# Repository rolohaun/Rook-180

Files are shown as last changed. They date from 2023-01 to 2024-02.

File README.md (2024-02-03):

# Rook 180

# PLEASE NOTE THIS IS OUT OF DATE

NEWEST VERSION HERE
https://www.printables.com/model/748800-bastion-3d-printer

Welcome to the DIY 3D Printer called Rook 180!

This is a 180x180 build volume printer based on the original Rook

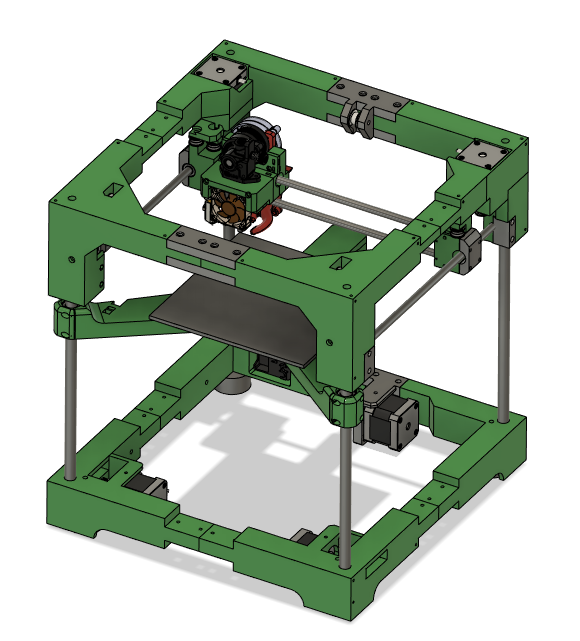
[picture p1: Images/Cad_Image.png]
image of Rook 3D Printer


### PLEASE NOTE THIS PRINTER IS A WORK IN PROGRESS!

The goal of this printer is to make a cheap easy to build 3D printer than can be built by anyone.

## Features:

- 180 x 180 Build Volume
- 3D Printed Frame
- CoreXY
- Triple Belted Z
- Only Roughly $400 USD in cost

## Build F.A.Q

- I print with 3 walls and 15 percent infill, if you want stronger go 4 walls 20 percent infill should be plenty
- I use PLA for the prototype and it worked well, ABS and ASA would be great too
- This printer uses all F695 bearings with some 20t idlers for the belted Z

### [BOM on Google Drive](https://docs.google.com/spreadsheets/d/1l0jujA7NeqoZIqLFWoQa9GS_q04f8Wfkya9Il5d2ubA/edit#gid=0)

### [Support me on Patreon](https://www.patreon.com/rolohaun)

### [My Discord](https://discord.gg/jJSwTtkX6T)

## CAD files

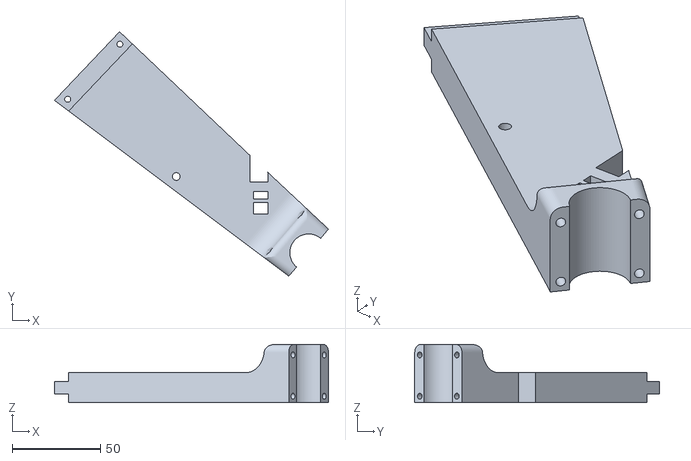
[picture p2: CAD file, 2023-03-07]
STL/Bed/Right_Bed_Mount.stl
155.0 x 138.3 x 33.0

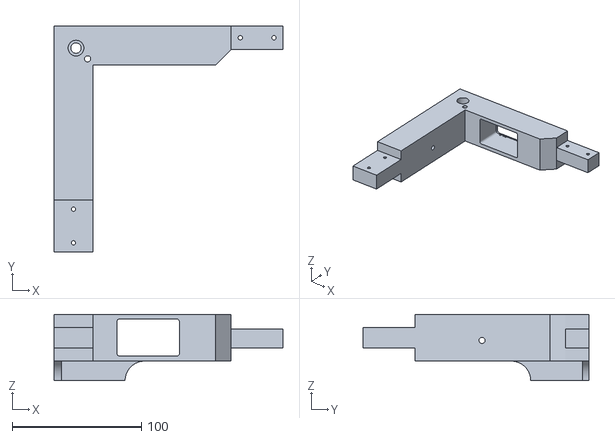
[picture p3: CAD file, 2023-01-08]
STL/Frame/Bottom Frame/BOTTOM_Rear_Left_Bottom_Frame.stl
177.0 x 174.5 x 51.1

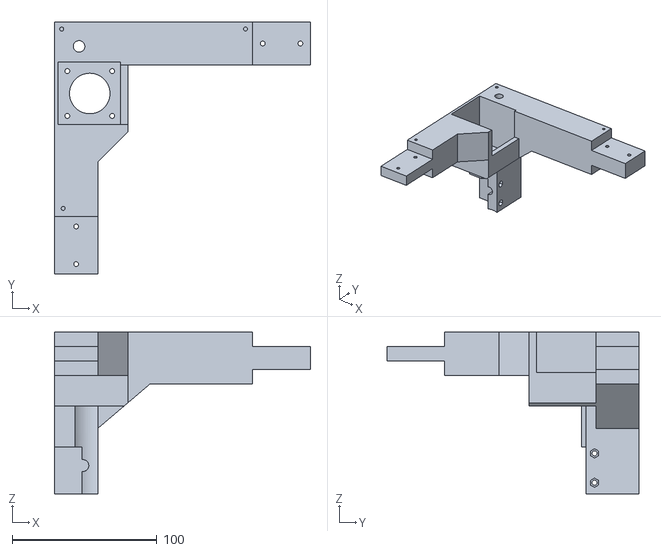
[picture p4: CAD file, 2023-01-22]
STL/Frame/Top Frame/TOP_Left_Rear_Frame.stl
177.0 x 174.5 x 112.0

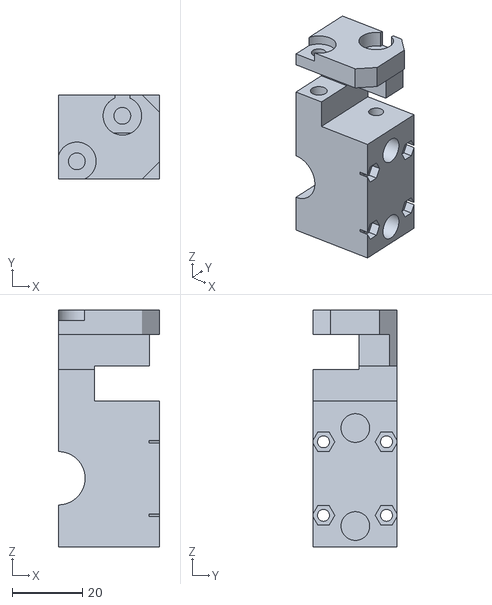
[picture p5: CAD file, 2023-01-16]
STL/Gantry/Y_Carriage_Left.stl
28.9 x 24.0 x 67.7

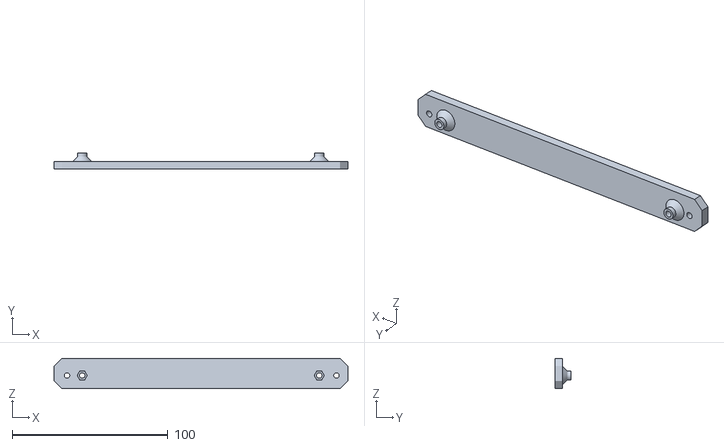
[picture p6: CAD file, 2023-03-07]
STL/MKS_Monster_8_Mount.stl
188.5 x 10.5 x 19.4

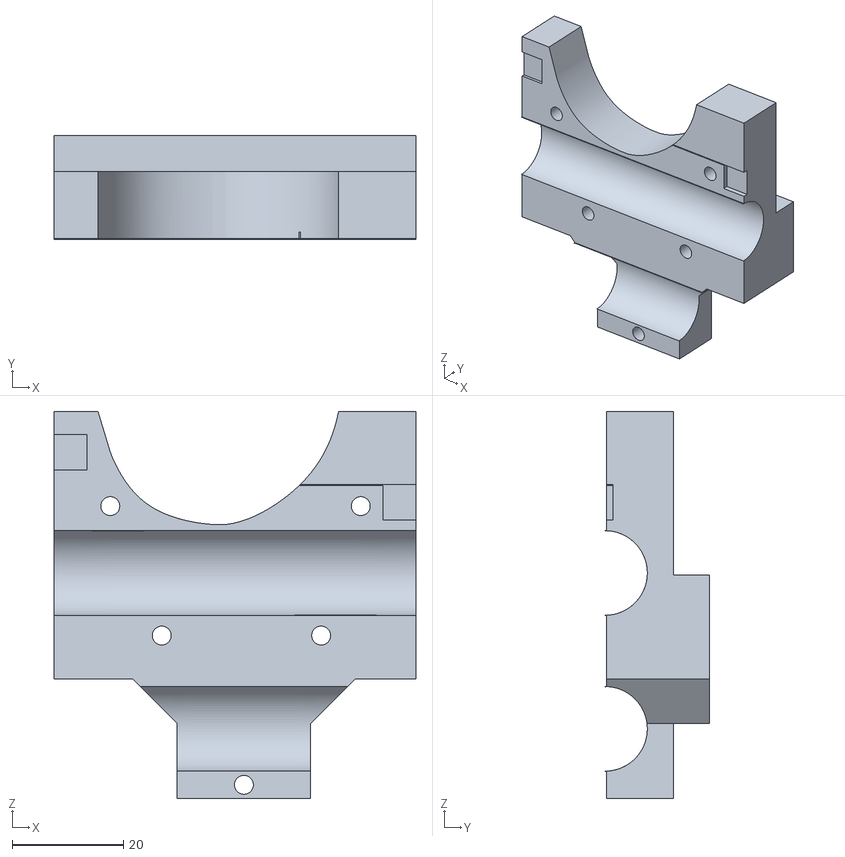
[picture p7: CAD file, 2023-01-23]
STL/Toolhead/X_Carriage_Rear.stl
65.0 x 18.7 x 69.5

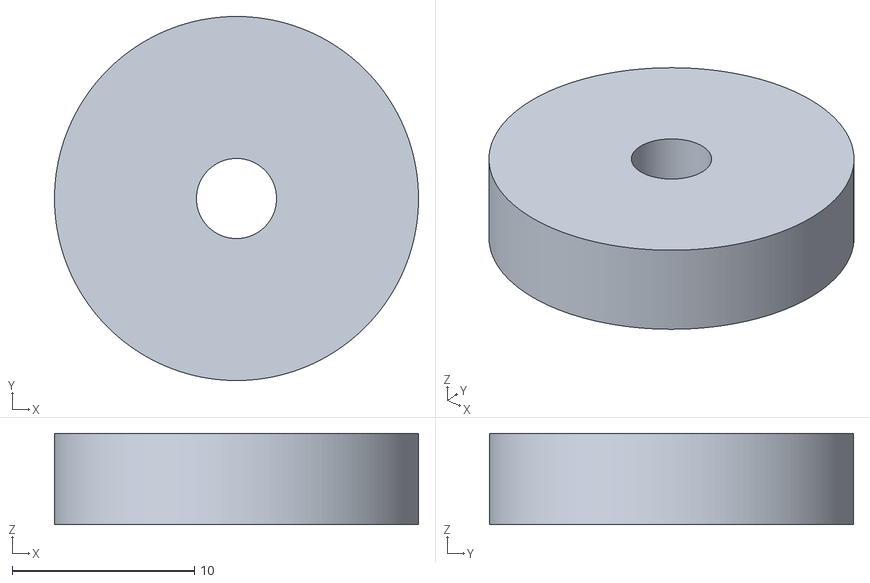
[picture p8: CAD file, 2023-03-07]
STL/Bed/4 x Prusa_Bed_Mount.stl
20.0 x 20.0 x 5.00

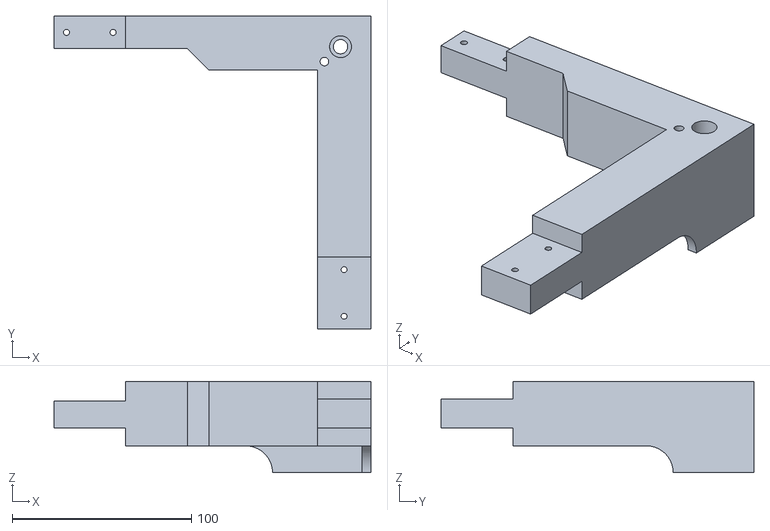
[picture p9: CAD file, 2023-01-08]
STL/Frame/Bottom Frame/BOTTOM_Rear_Right_Bottom_Frame.stl
177.0 x 174.5 x 51.1

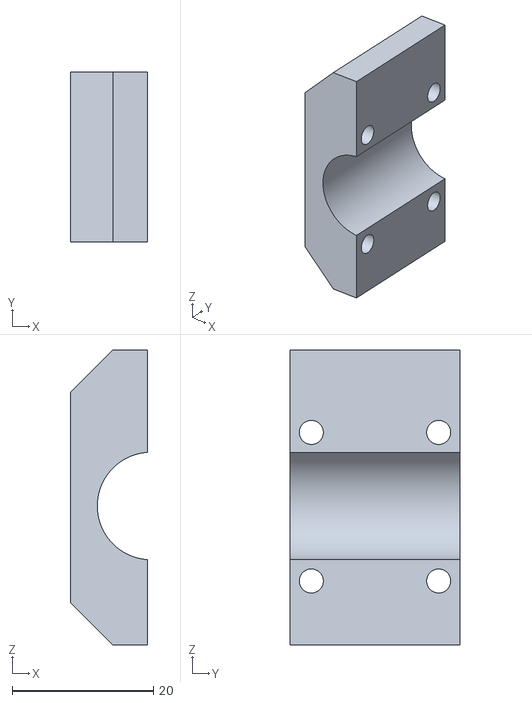
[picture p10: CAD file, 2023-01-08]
STL/Gantry/Y_Left_Carriage_Clamp.stl
10.9 x 24.0 x 41.7

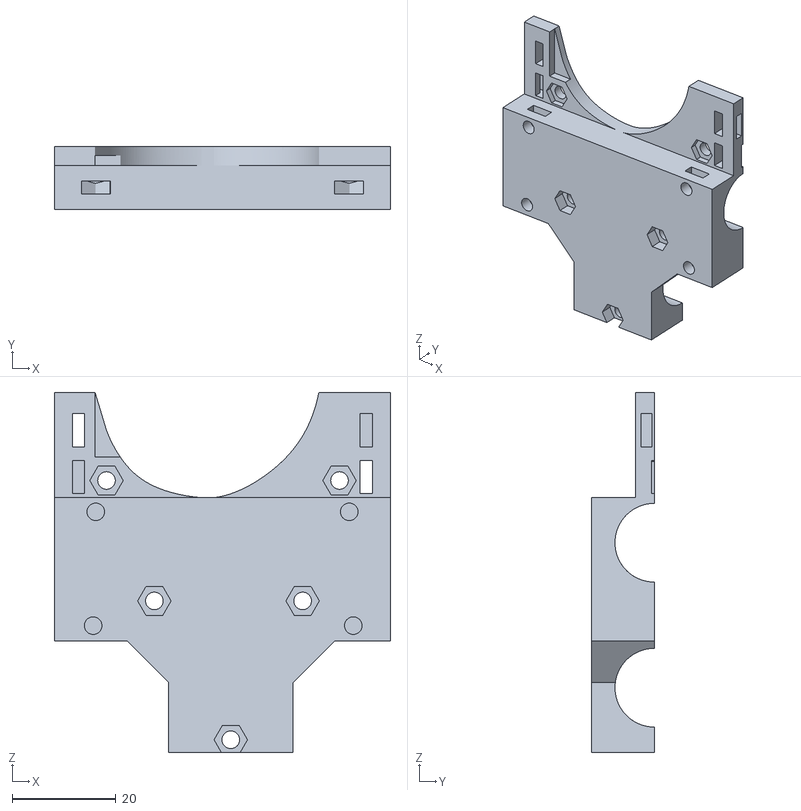
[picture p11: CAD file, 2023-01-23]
STL/Toolhead/X_Carriage_Front.stl
65.0 x 12.2 x 69.5

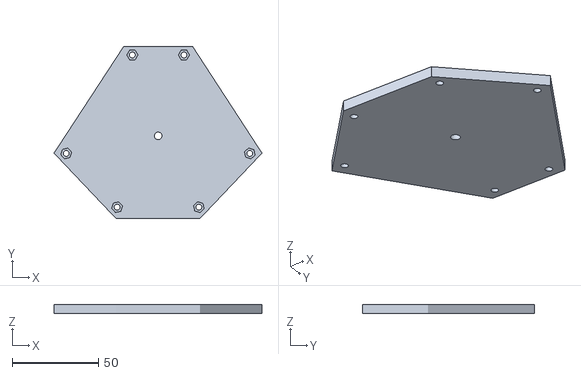
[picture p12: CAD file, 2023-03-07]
STL/Bed/Bed_Center_Top.stl
120.5 x 99.8 x 5.00

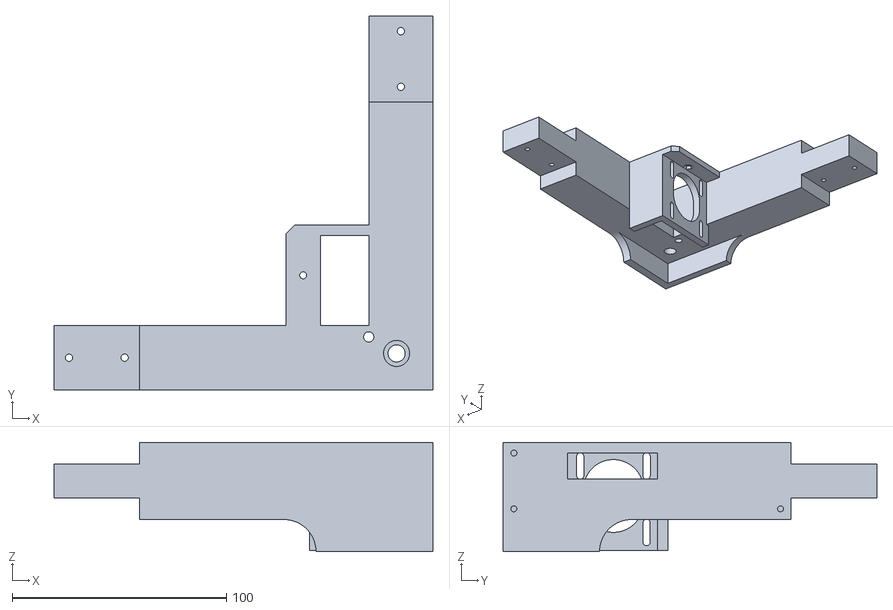
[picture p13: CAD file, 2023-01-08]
STL/Frame/Bottom Frame/BOTTOM_Front_Right_Bottom_Frame.stl
177.0 x 174.5 x 51.1

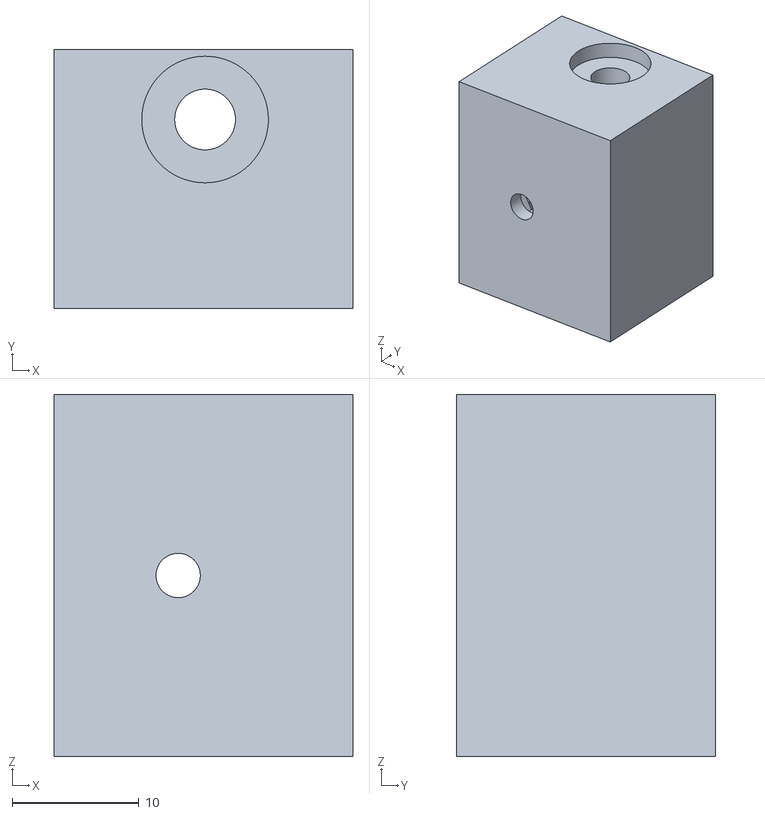
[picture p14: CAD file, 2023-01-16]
STL/Frame/Top Frame/Right_Idler_Cartridge.stl
23.6 x 20.5 x 28.6

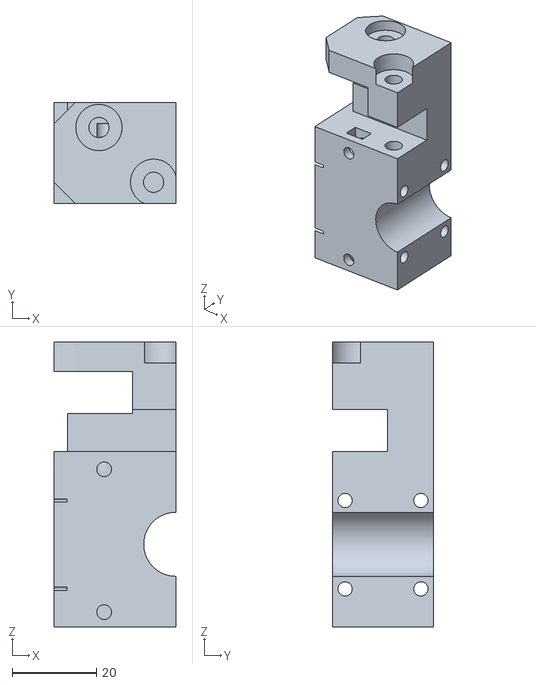
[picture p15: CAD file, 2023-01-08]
STL/Gantry/Y_Carriage_Right.stl
28.9 x 24.0 x 67.7

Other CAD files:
STL/Frame/Top Frame/TOP_Right_Rear_Frame.stl
STL/Toolhead/Toolhead_TD6S.stl
STL/Bed/Left_Bed_Mount.stl
STL/Frame/Bottom Frame/BOTTOM_Front_Left_Bottom_Frame.stl
STL/Bed/Bed_Center_Bottom.stl
STL/Bed/Left_Bed_Bearing_Clamp.stl
STL/Bed/Rear_Bed_mount.stl
STL/Bed/Right_Bed_Bearing_Clamp.stl
STL/Frame/Bottom Frame/1 x Rear_Lower_Brace_With_Motor_Mount.stl
STL/Frame/Bottom Frame/3 x Frame_Lower_Brace.stl
STL/Frame/Bottom Frame/3 x Frame_Upper_Brace.stl
STL/Frame/Top Frame/1 x Rear_Upper_Brace.stl
STL/Frame/Top Frame/3 x Frame_Lower_Brace.stl
STL/Frame/Top Frame/3 x Frame_Upper_Brace.stl
STL/Frame/Top Frame/Front_Left_Y_Frame_Clamp.stl
STL/Frame/Top Frame/Front_Right_Y_Frame_Clamp.stl
STL/Frame/Top Frame/Left_Idler_Cartridge.stl
STL/Frame/Top Frame/Rear_Left_Y_Frame_Clamp.stl
STL/Frame/Top Frame/Rear_Right_Y_Frame_Clamp.stl
STL/Frame/Top Frame/TOP_Left_Front_Frame.stl
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

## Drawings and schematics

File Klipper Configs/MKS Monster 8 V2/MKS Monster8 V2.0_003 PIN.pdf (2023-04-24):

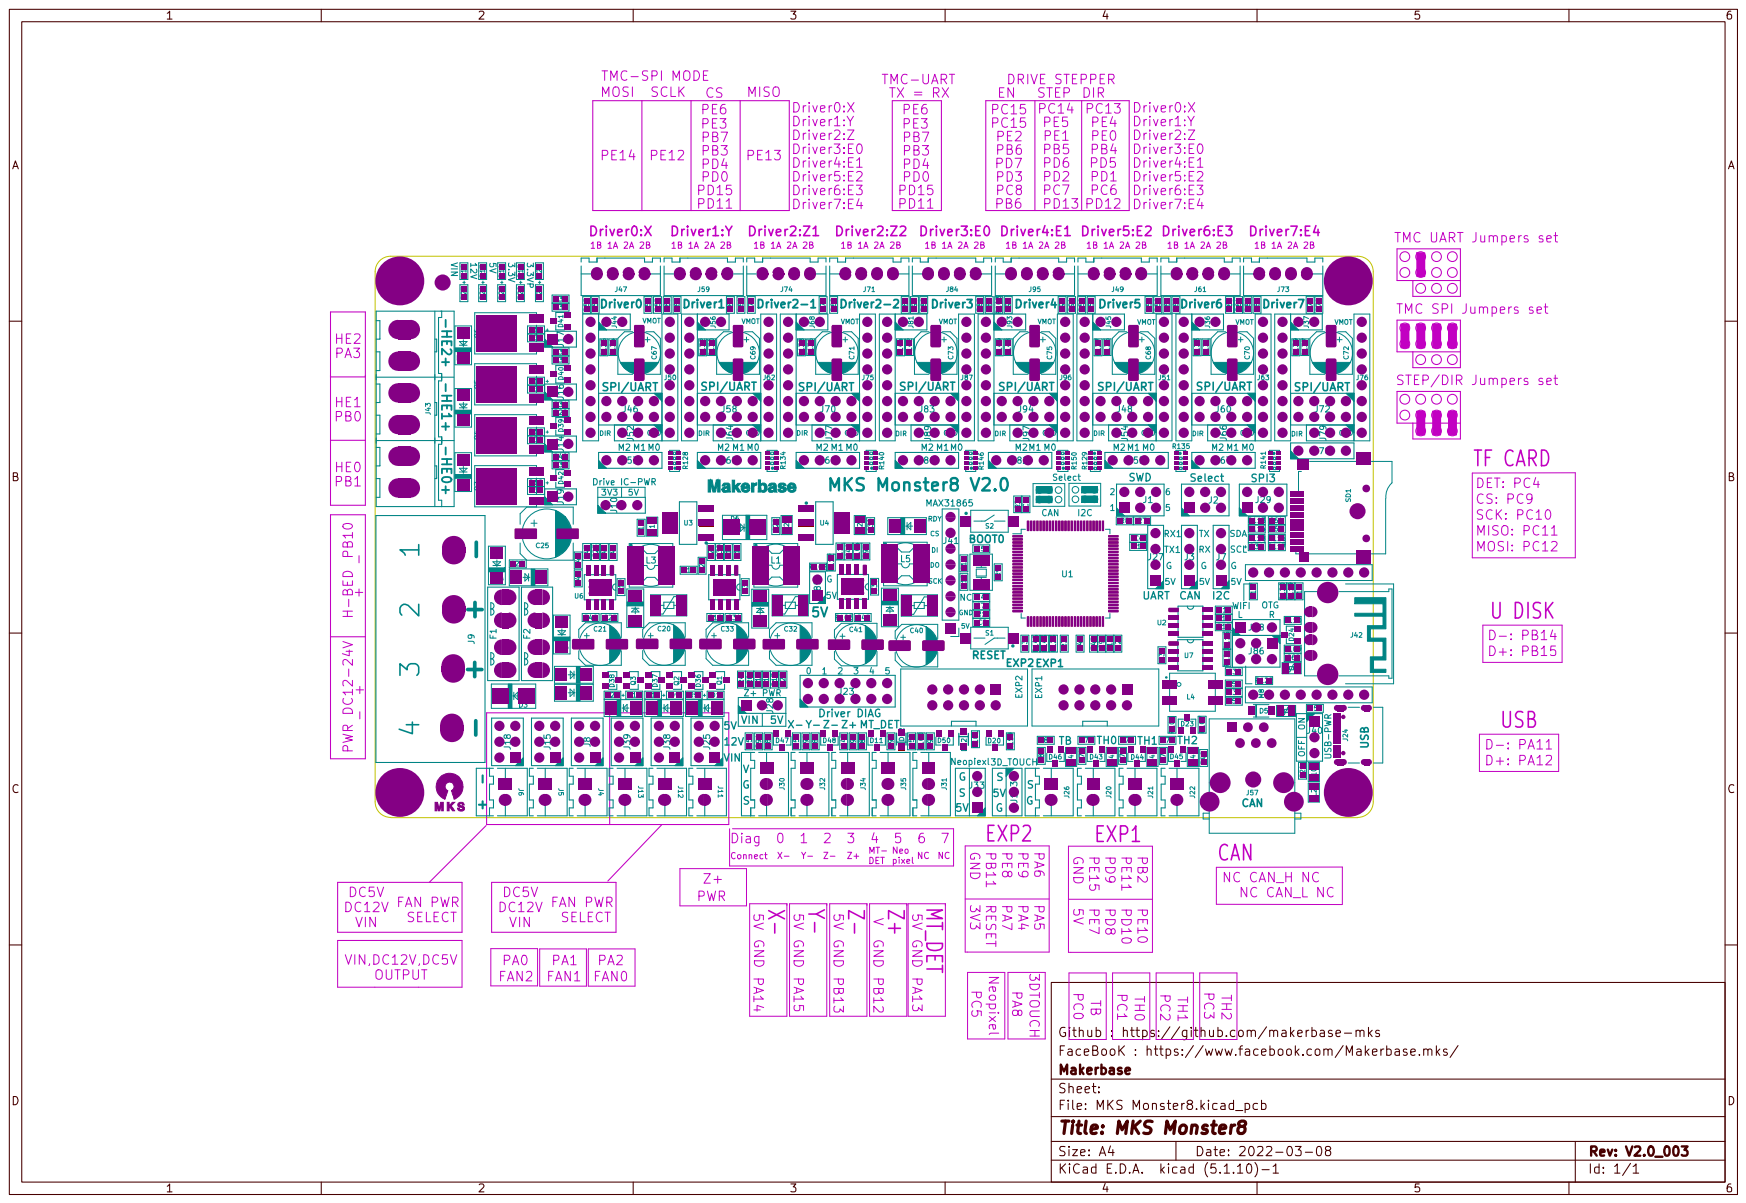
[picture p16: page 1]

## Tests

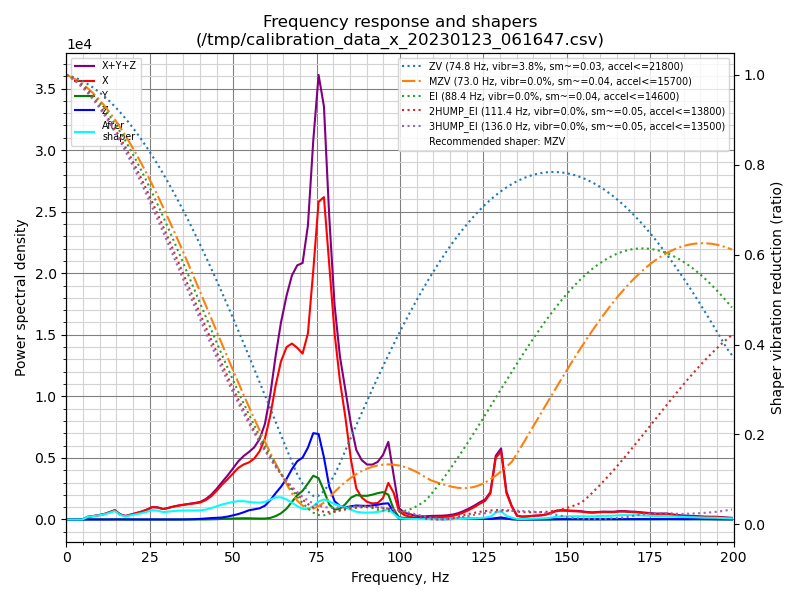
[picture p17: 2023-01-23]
Input Shaper Graphs/shaper_calibrate_x.png

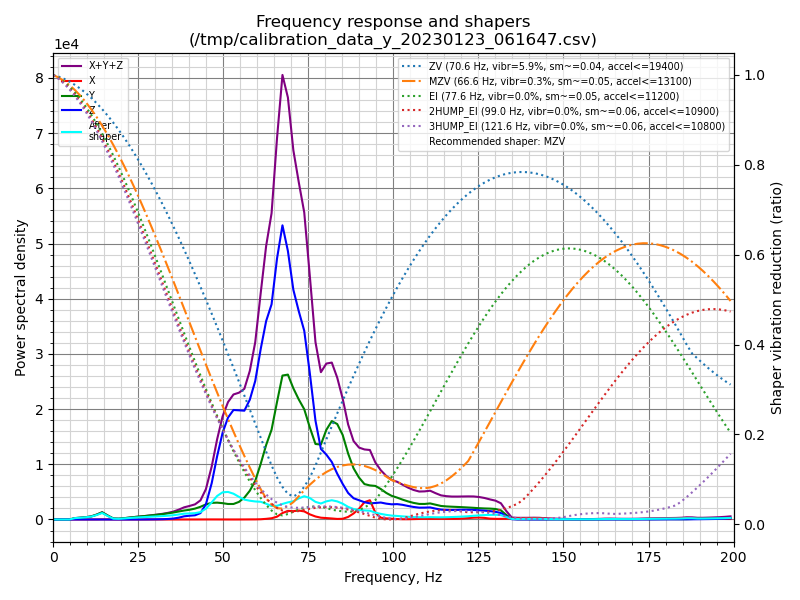
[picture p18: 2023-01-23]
Input Shaper Graphs/shaper_calibrate_y.png

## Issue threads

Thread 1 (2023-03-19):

Filament needed to print parts

kozross, 2023-03-19:
Roughly how much filament would you need to print the parts required for assembly, given the settings specified here?

rolohaun, 2023-03-20:
1.5 spools

MartijnGevaert, 2023-09-25:
Maybe this can be added to the BoM?

rolohaun, 2023-09-25:
one the release of MK1 is done I will add filament amount to the BOM

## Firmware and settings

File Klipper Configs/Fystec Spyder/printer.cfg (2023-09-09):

[include mainsail.cfg]
#[include adxl.cfg]

[gcode_macro PRINT_START]
#   Use PRINT_START for the slicer starting script - PLEASE CUSTOMISE THE SCRIPT
gcode:       
    # Parameters
    #{% set bedtemp = params.BED|int %}
    {% set hotendtemp = params.HOTEND|int %}
    #M190 S{bedtemp}
    G28
    Z_TILT_ADJUST
    M109 S{hotendtemp}
	
	

# Stepper Configs
[stepper_x]
# connected to X Stepper on SPIDER
step_pin: PE11
dir_pin: PE10
enable_pin: !PE9
rotation_distance: 40
full_steps_per_rotation: 400
microsteps: 32
endstop_pin: tmc2209_stepper_x:virtual_endstop 
position_endstop: 0
position_max: 180
homing_speed: 50
homing_retract_dist: 0

[tmc2209 stepper_x]
# connected to X Stepper on SPIDER
uart_pin: PE7
run_current: .9
sense_resistor: 0.110
stealthchop_threshold: 0
interpolate: False
diag_pin: PB14
driver_SGTHRS: 130

[stepper_y]
# connected to Y Stepper on SPIDER
step_pin: PD8
dir_pin: PB12
enable_pin: !PD9
rotation_distance: 40
full_steps_per_rotation: 400
microsteps: 32
endstop_pin: tmc2209_stepper_y:virtual_endstop
position_endstop: 180
position_max: 180
homing_speed: 50
homing_retract_dist: 0

[tmc2209 stepper_y]
# connected to Y Stepper on SPIDER
uart_pin: PE15
run_current: .9
sense_resistor: 0.110
stealthchop_threshold: 0
interpolate: False
diag_pin: PB13 
driver_SGTHRS: 125

[stepper_z]
# connected to Z Stepper on SPIDER
step_pin: PD14
dir_pin: PD13
enable_pin: !PD15
rotation_distance: 40
microsteps: 32
endstop_pin: probe:z_virtual_endstop
position_min: -10
position_max: 180
homing_speed: 50
homing_retract_dist: 0

[tmc2209 stepper_z]
# connected to Z Stepper on SPIDER
uart_pin: PD10
run_current: .5
sense_resistor: 0.110
stealthchop_threshold: 0
interpolate: False


[stepper_z1]
# connected to E0 Stepper on SPIDER
step_pin: PD5
dir_pin: PD6
enable_pin: !PD4
rotation_distance: 40
microsteps: 32
endstop_pin: probe:z_virtual_endstop 

[tmc2209 stepper_z1]
# connected to E0 Stepper on SPIDER
uart_pin: PD7
run_current: .5
sense_resistor: 0.110
stealthchop_threshold: 0
interpolate: False


#------------------------------------------------------------------------------------
[stepper_z2]
# connected to E1 Stepper on SPIDER
step_pin: PE6
dir_pin: !PC13
enable_pin: !PE5
rotation_distance: 40
microsteps: 32
endstop_pin: probe:z_virtual_endstop

[tmc2209 stepper_z2]
# connected to E1 Stepper on SPIDER
uart_pin: PC14
run_current: .5 
sense_resistor: 0.110
stealthchop_threshold: 0
interpolate: False


# Extruder0
[extruder]
# connected to E4 Stepper on SPIDER
step_pin: PE2
dir_pin: !PE4
enable_pin: !PE3
rotation_distance: 4.4765598
microsteps: 32
nozzle_diameter: 0.400
pressure_advance: 0.03
pressure_advance_smooth_time: 0.040
filament_diameter: 1.750	
# connected to Thermistor0 on SPIDER
sensor_type: ATC Semitec 104GT-2
sensor_pin: PC0
min_extrude_temp: 0
min_temp: 0
max_temp: 300
heater_pin: PB15
max_power: 1.0
max_extrude_only_distance: 1400.0
max_extrude_only_velocity: 120.0
max_extrude_only_accel: 1500.0
max_extrude_cross_section: 20000.0

[tmc2209 extruder]
# connected to E4 Stepper on SPIDER
uart_pin: PC15
run_current: 0.4
sense_resistor: 0.110
stealthchop_threshold: 0
interpolate: False
# connected to Heater0 on SPIDER


# Fans  
# Hotend Cooling Fan
[heater_fan my_nozzle_fan]
# connected to Fan0 on SPIDER - 12v Fan
pin: PA13
max_power: 1.0
#kick_start_time: 0.5
heater: extruder
heater_temp: 50.0
 
# print cooling fan
[fan]
# connected to Fan1 on SPIDER - 12v Fan
pin: PB2 #PC8
max_power: 1.0
kick_start_time: 0.500

[bltouch]
sensor_pin: ^PA0
control_pin: PA2
x_offset: -20
y_offset:  5
z_offset: 1.2
probe_with_touch_mode: true
stow_on_each_sample: false

[z_tilt]
horizontal_move_z: 5
z_positions:
    -40, -2
    90, 250
    220, -2
points:
    40, 30
    110, 170
    180, 30
speed: 150
horizontal_move_z: 5
retries: 7
retry_tolerance: 0.015

[safe_z_home]
home_xy_position: 90, 90 # Change coordinates to the center of your print bed
speed: 50
z_hop: 0                 # Move up 10mm
z_hop_speed: 5


# MCU SPIDER
[mcu] 
serial: /dev/serial/by-id/usb-Klipper_stm32f446xx_2D0030001951303439363932-if00
restart_method: command

# EXP1 / EXP2 (display) pins
[board_pins]
aliases:
    # EXP1 header
    EXP1_1=PC9, EXP1_2=PA8,
    EXP1_3=PC11, EXP1_4=PD2,
    EXP1_5=PC10, EXP1_6=PC12,    # Slot in the socket on this side
    EXP1_7=PD0, EXP1_8=PD1,
    EXP1_9=<GND>, EXP1_10=<5V>,

    # EXP2 header
    EXP2_1=PA6, EXP2_2=PA5,
    EXP2_3=PC6, EXP2_4=PA4,
    EXP2_5=PC7, EXP2_6=PA7,      # Slot in the socket on this side
    EXP2_7=PB10, EXP2_8=<RST>,
    EXP2_9=<GND>, EXP2_10=<5V>



#Gcode G2/G3 Arc Support
[gcode_arcs]
resolution: 0.1

#Printer Speeds and Accels
[printer]
kinematics: corexy
max_velocity: 300
max_accel: 10000 # change this to 7500 after commissioning
max_z_velocity: 15   # may be able to increase to 15 after comissioning.
max_z_accel: 50
square_corner_velocity: 4 # start at 8, but then increase once you're sure assembly is sound


# Motor and Heater Idle Timeout
[idle_timeout]
timeout: 6000

#*# <---------------------- SAVE_CONFIG ---------------------->
#*# DO NOT EDIT THIS BLOCK OR BELOW. The contents are auto-generated.
#*#
#*# [extruder]
#*# control = pid
#*# pid_kp = 21.086
#*# pid_ki = 1.673
#*# pid_kd = 66.420
#*#
#*# [input_shaper]
#*# shaper_type_x = mzv
#*# shaper_freq_x = 78.0
#*# shaper_type_y = 2hump_ei
#*# shaper_freq_y = 65.6

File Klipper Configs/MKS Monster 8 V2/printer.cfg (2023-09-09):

[include mainsail.cfg]
[include pinout_aliases.cfg]
[include mks_mini_12864_v3.cfg]
#[include adxl.cfg]

[printer]
kinematics: corexy
max_velocity: 300
max_accel: 5000 # change this to 7500 after commissioning
max_z_velocity: 15   # may be able to increase to 15 after comissioning.
max_z_accel: 50
square_corner_velocity: 4 # start at 8, but then increase once you're sure assembly is sound

[mcu] 
serial: /dev/serial/by-id/usb-Klipper_stm32f407xx_40001F000C50304B57383620-if00
restart_method: command

[gcode_macro CALIBRATE_BED_LEVEL]
gcode:
  G28
  Z_TILT_ADJUST
  BED_MESH_CALIBRATE

[gcode_macro PRINT_START]
#   Use PRINT_START for the slicer starting script - PLEASE CUSTOMISE THE SCRIPT
gcode:       
    M109 150 # prehead nozzle a bit
    CALIBRATE_BED_LEVEL
    {% set hotendtemp = params.HOTEND|int %}
    # Prime line
    G1 Z0.28 F240
    G92 E0
    G1 X179.0 Y140 E10 F1500 ; prime the nozzle
    G1 X179.3 Y140 F5000
    G92 E0
    G1 X179.3 Y10 E10 F1200 ; prime the nozzle
    G92 E0


# Stepper Configs
[stepper_x]
# connected to X Stepper
step_pin: PC14
dir_pin: PC13
enable_pin: !PC15
rotation_distance: 40
full_steps_per_rotation: 200
microsteps: 32
endstop_pin: tmc2209_stepper_x:virtual_endstop 
position_endstop: -10
position_min: -10
position_max: 180
homing_speed: 30
homing_retract_dist: 0

[tmc2209 stepper_x]
# connected to X Stepper
uart_pin: PE6
run_current: .9
sense_resistor: 0.110
stealthchop_threshold: 0
interpolate: False
diag_pin: PA14
driver_SGTHRS: 75

[stepper_y]
# connected to X Stepper
step_pin: PE5
dir_pin: PE4
enable_pin: !PC15
rotation_distance: 40
full_steps_per_rotation: 200
microsteps: 32
endstop_pin: tmc2209_stepper_y:virtual_endstop
position_endstop: 180
position_max: 180
homing_speed: 30
homing_retract_dist: 0

[tmc2209 stepper_y]
# connected to Y Stepper
uart_pin: PE3
run_current: .9
sense_resistor: 0.110
stealthchop_threshold: 0
interpolate: False
diag_pin: PA15 
driver_SGTHRS: 65

[stepper_z]
# connected to Z Stepper
step_pin: PE1
dir_pin: PE0
enable_pin: !PE2
rotation_distance: 40
microsteps: 32
endstop_pin: probe:z_virtual_endstop
position_min: -10
position_max: 180
homing_speed: 30
homing_retract_dist: 0

[tmc2209 stepper_z]
# connected to Z Stepper
uart_pin: PB7
run_current: .5
sense_resistor: 0.110
stealthchop_threshold: 0
interpolate: False

[stepper_z1]
# connected to E0 Stepper
step_pin: PB5
dir_pin: PB4
enable_pin: !PB6
rotation_distance: 40
microsteps: 32
endstop_pin: probe:z_virtual_endstop 

[tmc2209 stepper_z1]
# connected to E0 Stepper
uart_pin: PB3
run_current: .5
sense_resistor: 0.110
stealthchop_threshold: 0
interpolate: False


#------------------------------------------------------------------------------------
[stepper_z2]
# connected to E1 Stepper
step_pin: PD6
dir_pin: !PD5
enable_pin: !PD7
rotation_distance: 40
microsteps: 32
endstop_pin: probe:z_virtual_endstop

[tmc2209 stepper_z2]
# connected to E1 Stepper
uart_pin: PD4
run_current: .5 
sense_resistor: 0.110
stealthchop_threshold: 0
interpolate: False


# Extruder0
[extruder]
# connected to E4 Stepper
step_pin: PD13
dir_pin: !PD12
enable_pin: !PB6
rotation_distance: 4.4765598
microsteps: 32
nozzle_diameter: 0.400
pressure_advance: 0.03
pressure_advance_smooth_time: 0.040
filament_diameter: 1.750	

# connected to TH0
sensor_type: ATC Semitec 104GT-2
sensor_pin: PC1

min_extrude_temp: 0
min_temp: -200
max_temp: 999
# connected to HE0
heater_pin: PB1
max_power: 1.0
max_extrude_only_distance: 1400.0
max_extrude_only_velocity: 120.0
max_extrude_only_accel: 1500.0
max_extrude_cross_section: 20000.0

[tmc2209 extruder]
# connected to E4 Stepper
uart_pin: PD11
run_current: 0.4
sense_resistor: 0.110
stealthchop_threshold: 0
interpolate: False


# connected to Heater0
# Fans  
# Hotend Cooling Fan
[heater_fan my_nozzle_fan]
# connected to Fan0 - 24v Fan
pin: PA2
max_power: 1.0
#kick_start_time: 0.5
heater: extruder
heater_temp: 50.0
 
# print cooling fan
[fan]
# connected to Fan1 - 12v Fan
pin: PA1
max_power: 1.0
kick_start_time: 0.500

[bltouch]
sensor_pin: ^PC3
control_pin: PA8 # Connected to TH2
x_offset: -20
y_offset:  5
z_offset: 1.2
probe_with_touch_mode: true
stow_on_each_sample: false

[bed_mesh]
speed: 60
horizontal_move_z: 5
mesh_min: -20, 20
mesh_max: 130, 170
probe_count: 5, 5

[z_tilt]
horizontal_move_z: 5
z_positions:
    -40, -2
    90, 250
    220, -2
points:
    60, 180
    0, 30
    140, 30
speed: 100
horizontal_move_z: 5
retries: 7
retry_tolerance: 0.015

[safe_z_home]
home_xy_position: 90, 90 # Change coordinates to the center of your print bed
speed: 50
z_hop: 0                 # Move up 10mm
z_hop_speed: 5


#Gcode G2/G3 Arc Support
[gcode_arcs]
resolution: 0.1

# Motor and Heater Idle Timeout
[idle_timeout]
timeout: 6000

[respond]

#*# <---------------------- SAVE_CONFIG ---------------------->
#*# DO NOT EDIT THIS BLOCK OR BELOW. The contents are auto-generated.
#*#
#*# [extruder]
#*# control = pid
#*# pid_kp = 16.988
#*# pid_ki = 1.452
#*# pid_kd = 49.690

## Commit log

2023-01-16 updated M5 hole to allow 25mm
    [Y_Carriage_Left.stl]
2023-01-17 better orbiter 2 fitment
    [X_Carriage_Front.stl, X_Carriage_Rear.stl]
2023-01-22 allow for 40mm x and y motor
    [Rear_Bed_mount.stl, TOP_Left_Rear_Frame.stl, TOP_Right_Rear_Frame.stl]
2023-01-23 Fixed Belt tolerance
    [X_Carriage_Front.stl, X_Carriage_Rear.stl]
2023-01-23 Input shaping on current build
2023-03-25 Klipper config for MKS Monster8 V2 - beta
    [pinout_aliases.cfg, printer.cfg]
2023-03-25 beta version
    [mks_mini_12864_v2.cfg, pinout_aliases.cfg, printer.cfg]
2023-03-27 config update
    [printer.cfg]
2023-03-27 mks display v3
    [mks_mini_12864_v3.cfg]
2023-09-09 Z_tilt default values
    [printer.cfg]
